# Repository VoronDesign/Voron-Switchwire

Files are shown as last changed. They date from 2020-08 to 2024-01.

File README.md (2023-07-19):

# Voron Switchwire
**[CLICK HERE TO DOWNLOAD](https://voron.zip/done/VSW.zip)**

The above link includes the stealthburner toolhead files which are compatible with several of the printers in the Voron lineup. 
To keep things organized, StealthBurner’s files are maintained separately. 
the Stealthburner Repository can be browsed by clicking [HERE](https://github.com/VoronDesign/Voron-Stealthburner)

Image of Voron Switchwire

The official release of the Voron Switchwire 3d printer.  You can find the BOM and any other relevant information at the [Voron Design]( http://vorondesign.com/voron_switchwire) website.

Voron Logo

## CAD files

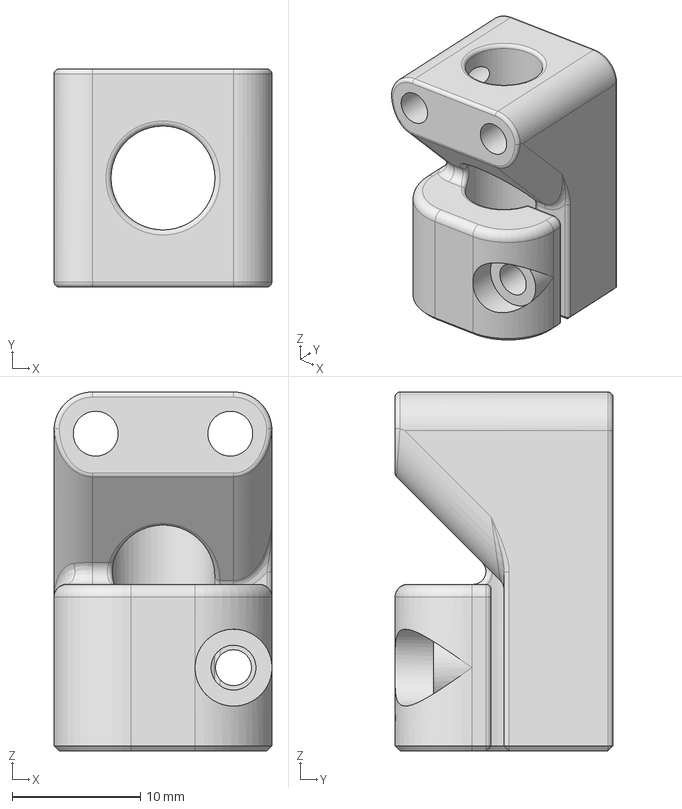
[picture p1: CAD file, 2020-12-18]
CAD/Pinion.step
17.0 x 17.0 x 28.0 mm

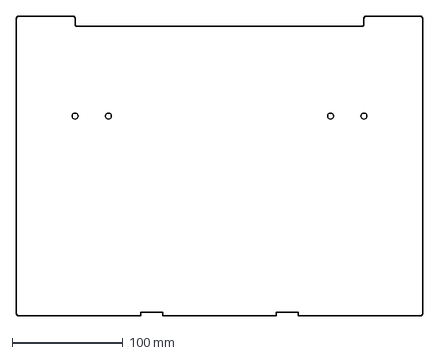
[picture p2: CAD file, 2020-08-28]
DXF/top_panel_abs.dxf
366.0 x 270.0 mm

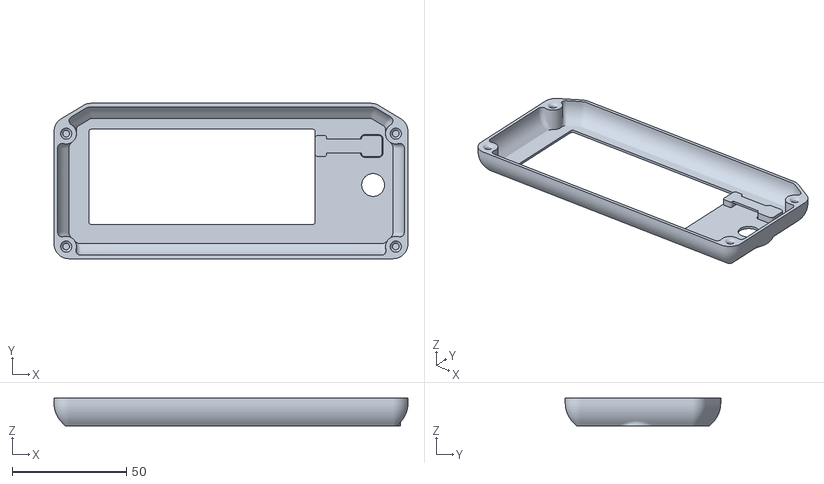
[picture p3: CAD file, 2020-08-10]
STL/Electronics/LCD/2004_(Prusa)/lcd_case_front_2004.stl
155.2 x 68.2 x 12.2

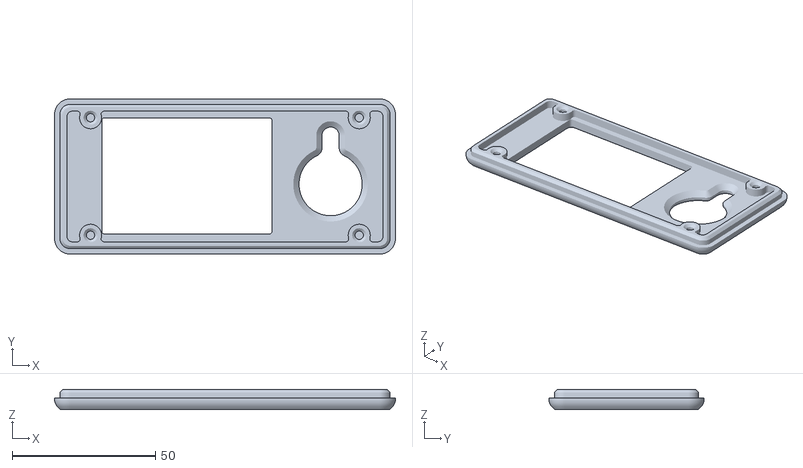
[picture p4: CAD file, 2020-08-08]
STL/Electronics/LCD/Mini12864/lcd_case_front_mini12864.stl
119.0 x 54.2 x 7.00

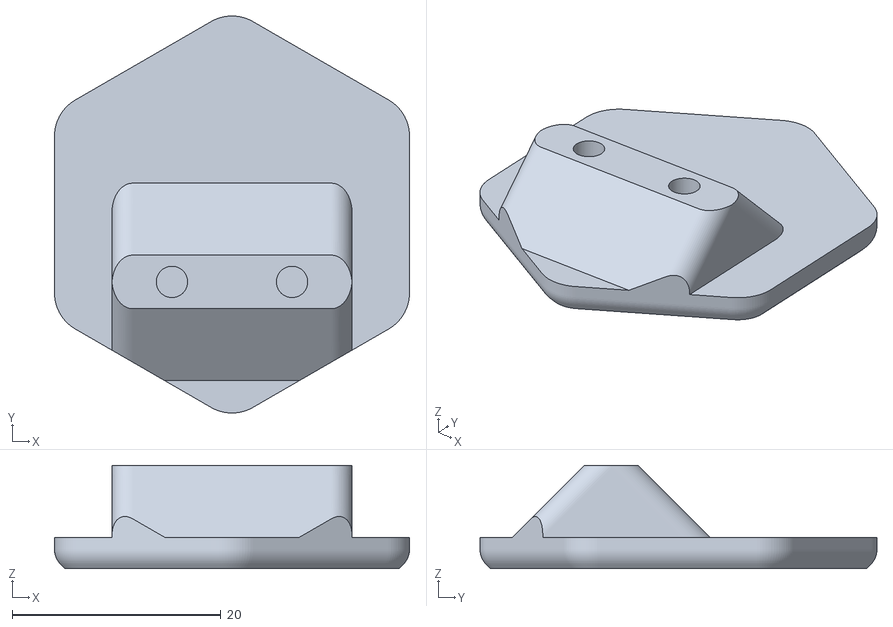
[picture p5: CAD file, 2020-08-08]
STL/Electronics/LCD/No_LCD/[a]_lcd_blank.stl
34.0 x 38.0 x 9.89

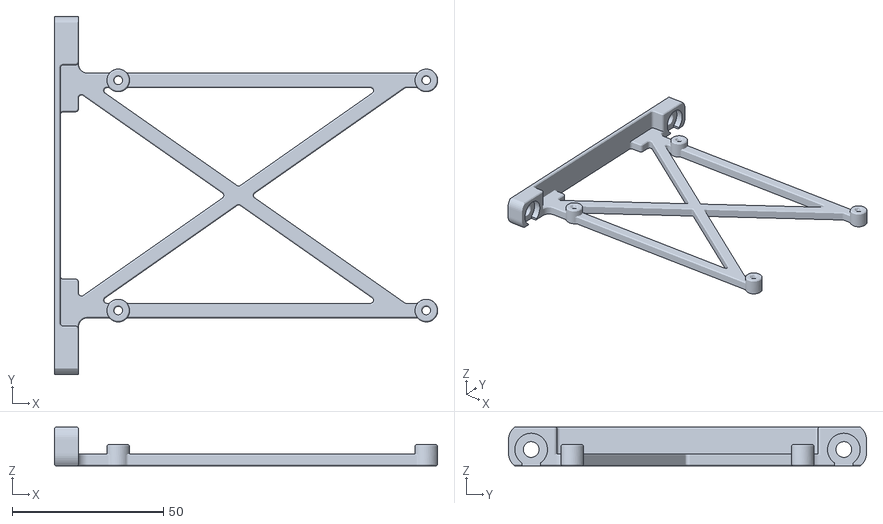
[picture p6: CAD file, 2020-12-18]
STL/Electronics/skr_mount.stl
126.8 x 118.3 x 12.8

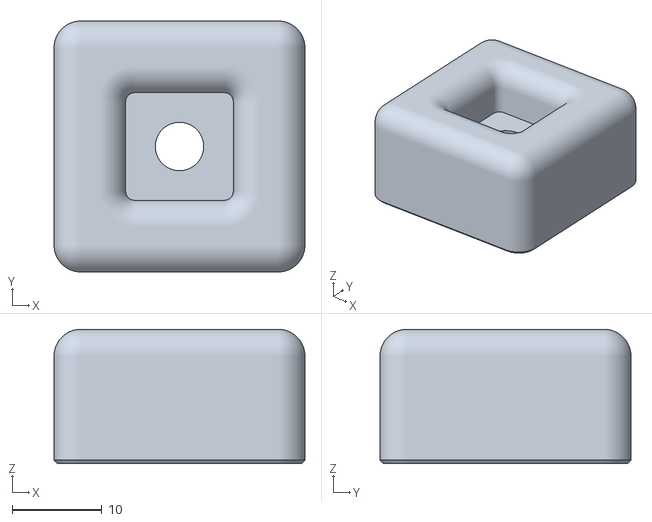
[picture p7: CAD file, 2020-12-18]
STL/foot_tpu_x4.stl
28.0 x 28.0 x 15.0

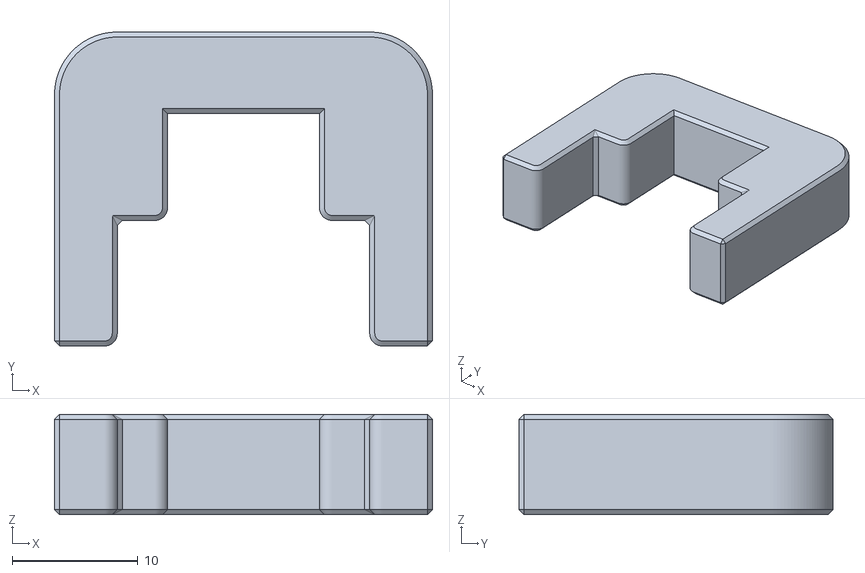
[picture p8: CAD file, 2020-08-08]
STL/Gantry/2020_MGN12_guide_x2.stl
30.1 x 25.0 x 8.00

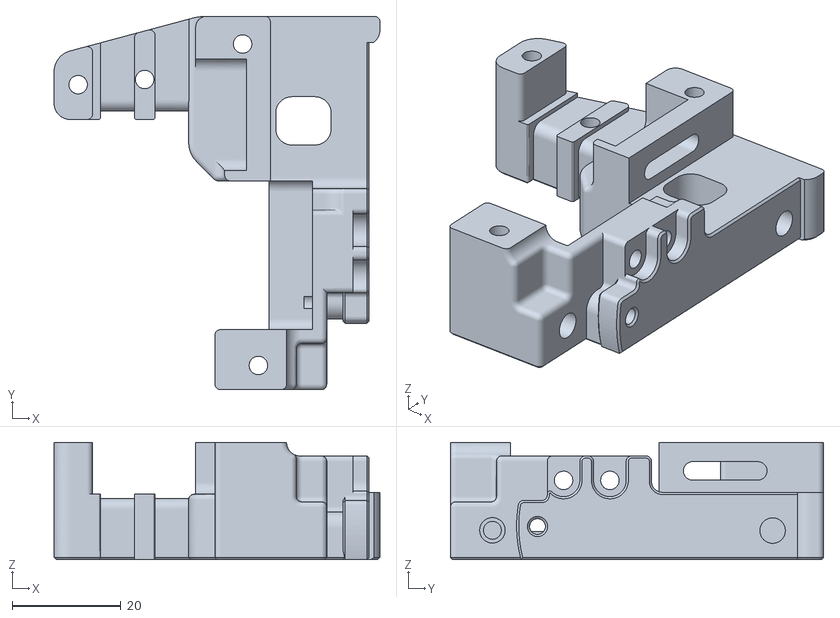
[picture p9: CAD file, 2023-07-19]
STL/Gantry/XZ_Axis/X_Carriage/x_frame_SW_left.stl
60.0 x 68.8 x 21.6

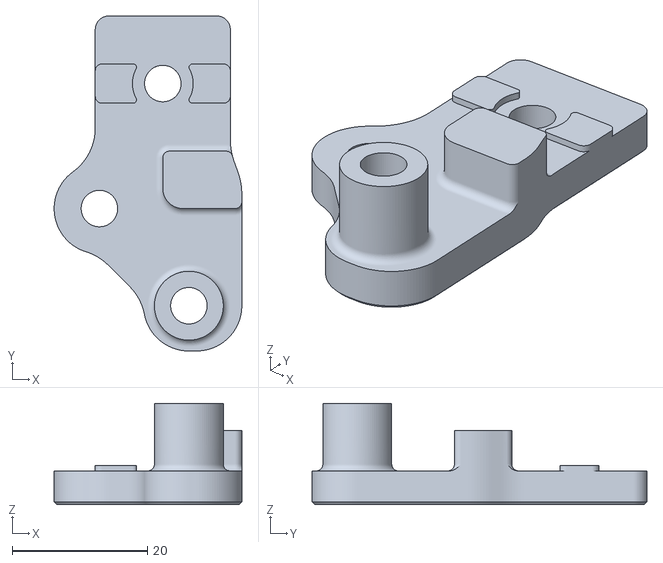
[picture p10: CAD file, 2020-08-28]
STL/Gantry/XZ_Axis/xz_block_right_b.stl
27.8 x 49.6 x 15.0

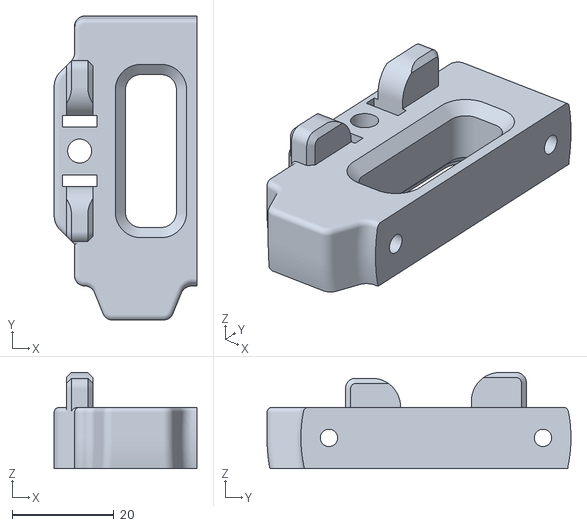
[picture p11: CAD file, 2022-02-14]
STL/Gantry/Y_Axis/y_belt_anchor_sensorless.stl
28.0 x 59.7 x 18.8

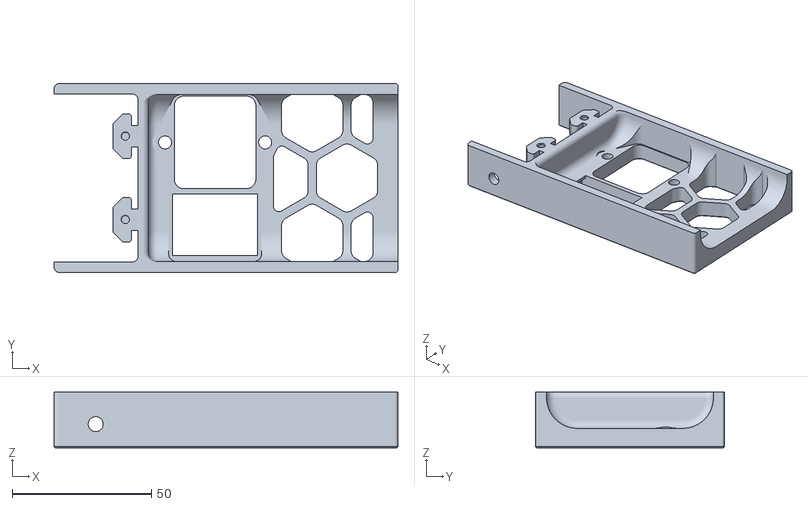
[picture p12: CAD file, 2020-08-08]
STL/Grills/grill_rear_left_filtered.stl
123.7 x 68.0 x 20.0

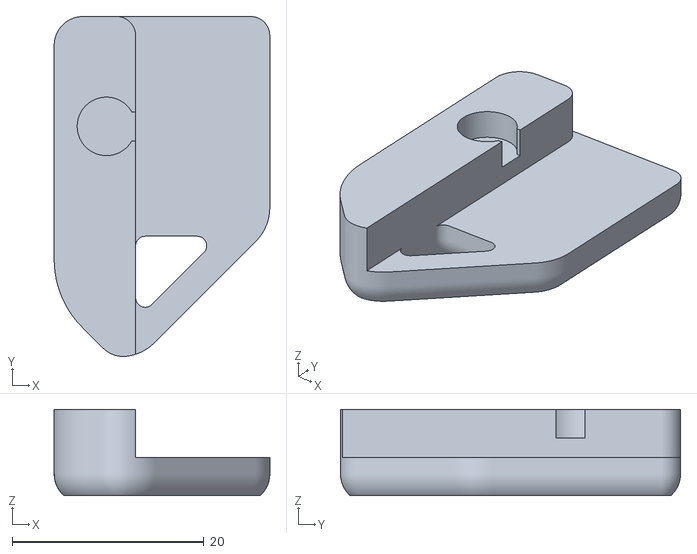
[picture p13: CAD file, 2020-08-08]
STL/Panel_Mounting/Doors/door_handle_b_x2.stl
22.5 x 35.5 x 9.00

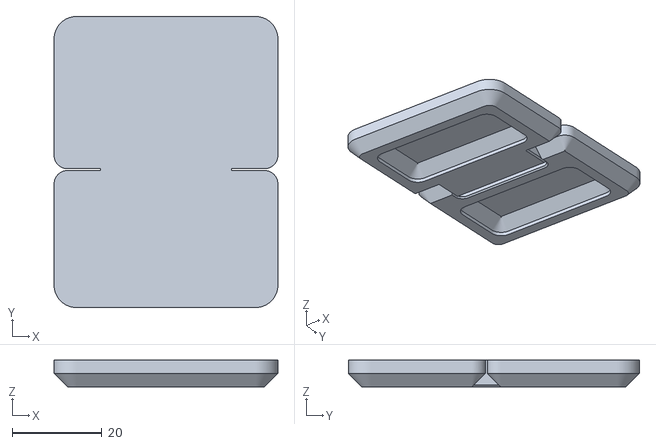
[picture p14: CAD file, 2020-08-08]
STL/Panel_Mounting/side_strap_x4.stl
50.0 x 65.0 x 6.00

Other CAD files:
DXF/deck_panel_right.dxf
STL/Electronics/LCD/2004_(Prusa)/lcd_case_rear_2004.stl
STL/Electronics/LCD/Mini12864/lcd_case_rear_mini12864.stl
STL/Electronics/skr_mount_rotated.stl
CAD/Pinion.f3d
DXF/bottom_panel.dxf
DXF/deck_panel_left.dxf
DXF/rear_panel.dxf
DXF/rear_panel_abs.dxf
DXF/side_panel_left.dxf
DXF/side_panel_left_abs.dxf
DXF/side_panel_right.dxf
DXF/side_panel_right_abs.dxf
DXF/top_panel.dxf
STL/Electronics/3030_wire_clip.stl
STL/Electronics/LCD/2004_(Prusa)/[a]_lcd_knob.stl
STL/Electronics/PS_2020_Mount_x2.stl
STL/Electronics/PS_3030_Mount_x2.stl
STL/Electronics/einsy_rambo_mount.stl
STL/Electronics/raspberry_pi_mount.stl
STL/Electronics/raspberry_pi_zero_shelf.stl
STL/Electronics/rs_25_mount.stl
STL/Electronics/skr_mini_e3_mount.stl
STL/Gantry/3030_MGN12_guide_x2.stl
STL/Gantry/XZ_Axis/X_Carriage/[a]_x_bearing_block.stl
STL/Gantry/XZ_Axis/X_Carriage/[a]_xz_belt_clip_x2.stl
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

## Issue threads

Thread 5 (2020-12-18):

Build guide of some sorts?

tobyworks, 2020-12-18:
Maybe I'm blind but i've searched for build guides or how to's or anything close to that and i couldn't find one? is it still on the to-do?

raymondh2, 2020-12-18:
The manual is in progress still

mild-lemon, 2020-12-31:
Any target date for a pre-alpha version of the manual?
I'm considering building a Switchwire, but without a preliminary manual I'm sort of lost. No idea on how to use the parts and printable jigs...

raymondh2, 2021-01-01:
There is an alpha version of the manual pinned in the Switchwire help channel on the Voron Discord.

Closed 2021-01-01.

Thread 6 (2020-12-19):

latch_shuttle.stl needs an [a] tag

9ary, 2020-12-19:
This part is red in the CAD and also in the V2.4 manual, it doesn't really matter in the end since it's not visible, but I figured I'd let y'all know anyway.

raymondh2, 2021-02-22:
Fixed in PR #19

Closed 2021-02-22.

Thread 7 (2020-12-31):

Update printer config to latest display menu options

raymondh2, 2020-12-31:
Current config files are based on old Klipper menu system. Suggest updating or removing them.

Closed 2021-02-06.

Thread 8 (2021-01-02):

Update printer to remove endstop_position from [stepper z]

jdlongenecker, 2021-01-02:
20201213: It is not valid to specify a Z "position_endstop" when using "probe:z_virtual_endstop". An error will now be raised if a Z "position_endstop" is specified with "probe:z_virtual_endstop". Remove the Z "position_endstop" definition to fix the error.

Closed 2021-02-06.

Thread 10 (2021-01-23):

Update to rotation_distance

raymondh2, 2021-01-23:
Update Klipper configs to use rotation_distance.

raymondh2, 2021-12-18:
Fixed in #31

Closed 2021-12-18.

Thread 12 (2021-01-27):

Error in assembly manual - page 10 and 14 - Wrong extrusions marked

internallabworks, 2021-01-27:
On page 10, the uprights for Z is marked for use for the bottom cross extrusions.
And on page 14 the cross extrusions are marked for use on Z
Example on page 10:
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

Makes the bottom look funky wide :)
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

jakep82, 2021-05-25:
This issue was reintroduced in the manual that was published 19 days ago. I just built my frame and discovered it called for the wrong extrusions, requiring me to disassemble and start over.

raymondh2, 2021-05-25:
This issue has been resolved by #13

Closed 2021-01-30.

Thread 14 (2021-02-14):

RE:  Addition to switchwire BOM

bigjoe4265, 2021-02-14:
6x6x3mm y-carriage spacers are available from McMaster.  Buy 10 instead of 9, price goes down from $2.11 to $1.79 each.  These should work, but haven't received them to verify the fit.

https://www.mcmaster.com/92871A009/

digitalfrost, 2021-02-22:
This information should be added to the sourcing guide not to the BOM.

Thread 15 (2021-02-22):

Missing Part in BOM: Bowden tube

digitalfrost, 2021-02-22:
On the page https://vorondesign.com/voron_switchwire when clicking on the BOM button, the BOM displayed and available for download as voron_switchwire_bom.csv seems to have a part missing.

It is not consistent with the information given in the sourcing guide: https://vorondesign.com/sourcing_guide?model=VS

Under the Misc section the
_Bowden Tube (4mm OD, 3mm ID) | 3m_
listed in the sourcing guide is missing from the downloadable sourcing guide.

raymondh2, 2021-02-22:
The 3mm id bowden tube is an optional item on Switchwire

Closed 2021-02-22.

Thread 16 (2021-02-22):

Inconsistencies between BOM and Sourcing Guide

digitalfrost, 2021-02-22:
There are inconsistencies between the sourcing guide https://vorondesign.com/sourcing_guide?model=VS and the BOM available on the  https://vorondesign.com/voron_switchwire page

Under the **Misc** section in the sourcing guide there is
_BMG Extruder Hardware Kit_
In the downloadable BOM this is listed in the **Motion** section as
_BMG Extruder Componnets Kit_

Under the **Motion** section in the sourcing guide there is
_Key-bak Super48 13oz_
this is listed in the **Misc** section in the downloadable BOM as
_Key-Bak Super 48 Retractable Keychain_
(I think this description is clearer as to what the item is)

renjie-teo, 2022-04-02:
Hi I've come across the link to this issue and would like to chime in for the keybak if it could be named as such:
Key-bak Super48 36" 13oz
The name is the full name listed on amazon as well so it would be clear to voron builders that they are supposed to purchase the 36" 13oz version instead of getting the 48" 8oz version by accident (perhaps also provide a warning since many who were unaware made the same mistake)

Thank you!

nemgrea, 2023-03-01:
this has been fixed

Closed 2023-03-01.

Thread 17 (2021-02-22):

BOM Electronics vs Sourcing Guide Electronics

digitalfrost, 2021-02-22:
The downloadable BOM has an **Electronics** section with 20 items.

The sourcing guide has an an **Electronics** section with 13 items.

The sourcing guide has a **"Controller"** section with 6 items which the downloadable BOM does not have
some of these items can be found in the **Electronics** section of the dowloadable BOM
for example
_SKR Mini E3 V2_
but others are not listed in the BOM at all for example
_MicroSD Card_

nemgrea, 2021-02-22:
things like the c14 cord and the micro usb cable do not benefit from having a line in the sourcing guide as local prices for these items are typically extremely variable and providing a link for you to buy one serves no benefit. all c14 cords are approved cords you cant buy a bad one, thus a guide for sourcing that component is not necessary

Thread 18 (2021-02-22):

Number of USB Cable A-male B-male

digitalfrost, 2021-02-22:
The BOM indicates

_USB Cable A-male B-male_  **QTY:** _2_

The sourcing guide indicates

_USB Cable A-male Mini B-male (Included with SKR Mini)_  **QTY:** _1_

nemgrea, 2021-02-22:
fixed

Closed 2021-02-22.

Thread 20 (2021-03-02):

The connector cover on directfeed is incompatiable with generic steppers

dingyifei, 2021-03-02:
I'm not sure which connector cover in the afterburner repo is the one in switchwire.

I got this wacky stepper motor from Taobao. With this motor, the following issues would occur:

- The cable cover will break in the installation
- The 20mm screws are to be too short to reach the threads
- The threaded insert on the clockwork can't be used to secure the cable cover since it's further away.

The image below is the stepper:
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

dingyifei, 2021-03-03:
NVM... looks like a mod exist for this issue

Closed 2021-03-03.

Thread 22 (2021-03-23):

[a] prefix in stl file names

tobyworks, 2021-03-23:
Some stl's have [a] as a prefix. What does this mean?

eddietheengineer, 2021-03-23:
This means that you can print them in an accent color to give your printer a bit more character 👍🏼

tobyworks, 2021-03-23:
Thanks for the rapid response!

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

Closed 2021-03-23.

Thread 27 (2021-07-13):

Incorrect / Old Klipper Configs.

cobramike, 2021-07-13:
After a full month of testing and fine tuning i made a Correct fysetc spider printer.cfg.
The old firmware are a very old Klipper config. Also extruder settings are incorrect. That is causing extreme heat Extruder Motor.
Here is my Printer.cfg for the fysetc spider

[https://pastebin.com/VuUeXtPq](url)

#####################################################################
# 	Printer settings
#####################################################################
[mcu]
serial: /dev/ttyAMA0
restart_method: command

[printer]
kinematics: corexz
max_velocity: 200
max_accel: 4000
max_accel_to_decel: 4000
max_z_velocity: 50
max_z_accel: 1000
square_corner_velocity: 4.0

[input_shaper]
shaper_freq_x: 52
shaper_freq_y: 54.5
shaper_type: mzv

[stepper_x]
step_pin: PE11
dir_pin: !PE10
enable_pin: !PE9
endstop_pin: ^PB14
position_endstop: 250
position_min: 0
position_max: 250
homing_speed: 70
homing_positive_dir: true
rotation_distance: 40
full_steps_per_rotation: 200
microsteps: 16

[tmc2209 stepper_x]
uart_pin: PE7
run_current: 0.5
hold_current: 0.3
interpolate: True
stealthchop_threshold: 250

[stepper_y]
step_pin: PD8
dir_pin: !PB12
enable_pin: !PD9
endstop_pin: ^PB13
position_endstop: 250
position_min: 0
position_max: 250
homing_speed: 70
homing_positive_dir: true
rotation_distance: 40
full_steps_per_rotation: 200
microsteps: 16

[tmc2209 stepper_y]
uart_pin: PE15
run_current: 0.6
hold_current: 0.4
interpolate: True
stealthchop_threshold: 250

[stepper_z]
step_pin: PD14
dir_pin: !PD13
enable_pin: !PD15
endstop_pin: probe:z_virtual_endstop
position_max: 235
homing_speed: 40
position_min: -3.0
rotation_distance: 40
full_steps_per_rotation: 200
microsteps: 16

[tmc2209 stepper_z]
uart_pin: PD10
run_current: 0.5
hold_current: 0.3
interpolate: True
stealthchop_threshold: 250

[bed_mesh]
speed: 150
horizontal_move_z: 10
mesh_min: 25,35.0
mesh_max: 225.0,220
probe_count: 6,6
algorithm: bicubic
fade_start: 1
fade_end: 10
fade_target: 0

[probe]
pin: PA3
x_offset: 0.0
y_offset: 25.0
#z_offset: 0
speed: 40.0

[homing_override]
axes: z
set_position_z: 0
gcode:
    G90
    G0 Z5 F500
    G28 X0 Y0
    G0 X125 Y100 F9000
    G28 Z0
    G0 Z5 F500

#####################################################################
# 	Extruder
#####################################################################

#	E0 on MCU X/Y
[extruder]
max_extrude_only_distance: 1000.0
step_pin: PD5
dir_pin: !PD6
enable_pin: !PD4
##	Update value below when you perform extruder calibration
##	If you ask for 100mm of filament, but in reality it is 98mm:
##	rotation_distance = <previous_rotation_distance> * <actual_extrude_distance> / 100
##  22.6789511 is a good starting point
rotation_distance: 22.225372078 	#Bondtech 5mm Drive Gears
##	Update Gear Ratio depending on your Extruder Type
##	Use 50:17 for Afterburner/Clockwork (BMG Gear Ratio)
##	Use 80:20 for M4, M3.1
gear_ratio: 50:17				#BMG Gear Ratio
microsteps: 16
full_steps_per_rotation: 200	#200 for 1.8 degree, 400 for 0.9 degree
nozzle_diameter: 0.400
filament_diameter: 1.75
heater_pin: PB15
##	Validate the following thermistor type to make sure it is correct
sensor_type: ATC Semitec 104GT-2
sensor_pin: PC0
min_temp: 10
max_temp: 270
max_power: 1.0
min_extrude_temp: 170
control = pid
pid_kp = 26.213
pid_ki = 1.304
pid_kd = 131.721
##	Try to keep pressure_advance below 1.0
pressure_advance: 0.05
##	Default is 0.040, leave stock
pressure_advance_smooth_time: 0.040

##	E0 on MCU X/Y
##	Make sure to update below for your relevant driver (2208 or 2209)
[tmc2209 extruder]
uart_pin: PD7
interpolate: false
run_current: 0.45
hold_current: 0.30
sense_resistor: 0.110
stealthchop_threshold: 0

#####################################################################
# 	END Extruder
#####################################################################

#####################################################################
# 	Probe Settings
#####################################################################
# Textured Bed
#[probe]
#z_offset = 4.910

# Flat Bed
[probe]
z_offset = 4.740

#####################################################################
# 	End Probe Settings
#####################################################################

[heater_bed]
heater_pin: PB4
sensor_type: NTC 100K MGB18-104F39050L32
sensor_pin: PC3
control = pid
pid_kp = 60.695
pid_ki = 1.073
pid_kd = 858.069
min_temp: 0
max_temp: 130

#######################################
#### Enclosure Temp Sensor Section ####
#######################################
[temperature_sensor enclosure_temp]
sensor_type: NTC 100K beta 3950
sensor_pin: PC1
min_temp: 0
max_temp: 100
gcode_id: C

#######################################
#### Raspberry Temp Sensor Section ####
#######################################
[temperature_sensor Pi]
sensor_type: rpi_temperature
min_temp: 0
max_temp: 90

[fan]
pin: PB2

# thermally controlled hotend fan
[heater_fan my_nozzle_fan]
pin: PB1
max_power: 1.0
kick_start_time: 0.100
heater: extruder
heater_temp: 50.0
fan_speed: 1.0

[virtual_sdcard]
path: ~/gcode_files

#####################################################################
#	Displays
#####################################################################

[display]
#   mini12864 LCD Display
lcd_type: uc1701
cs_pin: PC11
a0_pin: PD2
rst_pin: PC10
encoder_pins: ^PC6,^PC7
click_pin: ^!PA8
contrast: 63
#spi_bus: spi1
spi_software_mosi_pin: PA7
spi_software_miso_pin: PA6
spi_software_sclk_pin: PA5

[neopixel fysetc_mini12864]
#   To control Neopixel RGB in mini12864 display
pin: PC12
chain_count: 3
chain_count: 60
initial_RED: 0.1
initial_GREEN: 0.5
initial_BLUE: 0.0
color_order: RGB

#   Set RGB values on boot up for each Neopixel.
#   Index 1 = display, Index 2 and 3 = Knob
[delayed_gcode setdisplayneopixel]
initial_duration: 1
gcode:
    SET_LED LED=fysetc_mini12864 RED=1 GREEN=0 BLUE=0 INDEX=1 TRANSMIT=0
    SET_LED LED=fysetc_mini12864 RED=1 GREEN=0 BLUE=0 INDEX=2 TRANSMIT=0
    SET_LED LED=fysetc_mini12864 RED=1 GREEN=0 BLUE=0 INDEX=3

#####################################################################
#	LED Control
#####################################################################

# Chamber Lighting
[output_pin caselight]
pin: PB3
#max_power: 1.0
#kick_start_time: 0.5
pwm: true
shutdown_value: 0
value: 100
cycle_time: 0.01
scale: 100

# Lighting Control
[gcode_macro lights_off]
gcode:
    SET_PIN PIN=caselight VALUE=0

[gcode_macro lights_on]
gcode:
    SET_PIN PIN=caselight VALUE=100

#####################################################################
#	End LED Control
#####################################################################

#####################################################################
#	Macros
#####################################################################
[display_status]

[pause_resume]

[gcode_macro CANCEL_PRINT]
rename_existing: BASE_CANCEL_PRINT
gcode:
    M107
    TURN_OFF_HEATERS
    DISABLE_MOTORS
    CLEAR_PAUSE
    SDCARD_RESET_FILE
    BASE_CANCEL_PRINT

[gcode_macro PAUSE]
rename_existing: BASE_PAUSE
gcode:
    SAVE_GCODE_STATE NAME=PAUSE_state
    BASE_PAUSE
    G91
    G1 E-1.7 F2100
    G90
    _PARK_HEAD

[gcode_macro RESUME]
rename_existing: BASE_RESUME
gcode:
    G91
    G1 E1.7 F2100
    G91
    RESTORE_GCODE_STATE NAME=PAUSE_state MOVE=1
    BASE_RESUME

[gcode_macro DISABLE_MOTORS]
gcode:
    M18

[gcode_macro PRINT_START]
gcode:
    lights_on
    M117 Homing...
    M140 S{BED_TEMP}                         ; set bed final temp
    M104 S{EXTRUDER_TEMP}                         ; set extruder final temp
    M190 S{BED_TEMP}                         ; wait for bed final temp
    M109 S{EXTRUDER_TEMP}                         ; wait for extruder final temp
    BED_MESH_CLEAR

    G21 ; set units to millimeters
    G90 ; use absolute coordinates
    M83 ; use relative distances for extrusion
    G28 ; home all axes
    G1 Z20 F3000                   ; move nozzle away from bed
    BED_MESH_CALIBRATE
    G92 E0
    G90
    G0 X13 Y13 F6000
    G0 Z0.4
    G91
    G1 X120 E30 F1200
    G1 Y1
    G1 X-120 E30 F1200
    G92 E0
    G90
    G1 Z20.0 F3000
    G92 E0
    M117 Printing....

[gcode_macro PRINT_END]
#   Use PRINT_END for the slicer ending script - please customise for your slicer of choice
gcode:
    M400                           ; wait for buffer to clear
    G92 E0                         ; zero the extruder
    G1 E-1.0 F3600                ; retract filament
    G91                            ; relative positioning
    G0 Z1.00 X20.0 Y20.0 F20000    ; move nozzle to remove stringing
    TURN_OFF_HEATERS
    M107                           ; turn off fan
    G1 Z50 F3000                    ; move nozzle up 20mm
    G90                            ; absolute positioning
    G0  X0 Y220 F3600            ; park nozzle at rear
    BED_MESH_CLEAR
    M117 Finished!
    lights_off

#####################################################################
#	End Macros
#####################################################################

#*# <---------------------- SAVE_CONFIG ---------------------->
#*# DO NOT EDIT THIS BLOCK OR BELOW. The contents are auto-generated.
#*#

raymondh2, 2021-12-18:
Fixed in #31

Closed 2021-12-18.

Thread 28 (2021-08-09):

Assembly Manual repeats

spoonypirate, 2021-08-09:
In the Assembly manual, pages 74 and 75 for the Clockwork assembly are repeated, overwriting the instructions for the guidler and latch install.

TaffoFox, 2021-08-24:
I came to add this issue however you have done it already so thank you

Closed 2021-11-26.

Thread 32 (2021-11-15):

about MOS for sw

papagoWBT, 2021-11-15:
It says you need two MOSs in BoM, but it's not written in the sourcing guide. Do I have to buy MOS? How can I connect if I need MOS or not?

nemgrea, 2023-01-18:
fixed

Closed 2023-01-18.

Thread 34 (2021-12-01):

New printhead

Kevincondor, 2021-12-01:
hello,i'll like to use a Biqu H2 extruder on this,but cannot find a mount plate compatible

raymondh2, 2021-12-18:
You'll have to create your own as we don't have plans to support that extruder.

Closed 2021-12-18.

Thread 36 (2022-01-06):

switchwire stl and cad files out of synch

phongshader, 2022-01-06:
it looks like https://github.com/VoronDesign/Voron-Switchwire/blob/master/STL/Gantry/XZ_Axis/%5Ba%5D_upper_idler_support_b_left.stl and https://github.com/VoronDesign/Voron-Switchwire/blob/master/STL/Gantry/XZ_Axis/%5Ba%5D_upper_idler_support_b_right.stl are a different version than what is contained here https://github.com/VoronDesign/Voron-Switchwire/blob/master/CAD/Bowden_Dual_Adapter.step. Is it possible to get the updated files in step or f3d?

nemgrea, 2023-03-01:
the files youve linked are not the same parts, the bowden toolhead CAD is not intended to contain any of the idler parts

Closed 2023-03-01.

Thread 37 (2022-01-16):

Several files have been updated but there's no new release

maximilian-foerg, 2022-01-16:
I'm currently building a Switchwire and downloaded the latest Release from 28 of August in 2020. While printing the parts, I realized that an old version of the Afterburner is included in this release. A closer look into the repository unveiled that several STLs have been updated after this release. I think there should be a "Switchwire 1.1" or "Switchwire 1.0.1" release for that. At least the update of the Afterburner would have been worth it after all. People have been downloading an outdated release to build the switchwire for a year and a half now....

Closed 2022-12-20.

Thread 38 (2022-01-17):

Bearing block for SW unnecessary?

crashmaxx, 2022-01-17:
[a]_x_bearing_block_SW_beta0.stl is only used for SW, but the V2/Trident MGN12 carriage can mount to the same rail without this extra piece.

I suggest changing the SW carriage to mount directly to the rail, the same as V2/Trident. This would save an extra part, 4 screws, and 4 heat set inserts. I was able to redesign the original SW carriage in this way and have used it without issues.

Maybe I am missing an advantage of the extra block, but I suspect it exists simply because it was designed first. When Trident was designed, a better way to make the carriage was discovered.

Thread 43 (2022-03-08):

Manual only shows Probe Signal Wire Connection, Website is also unclear

ChaosBlades, 2022-03-08:
The Switchwire manual shows the diode and signal wire connection but just shows the positive and negative probe wires going to nothing.
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

The website could be more clear as well.
https://docs.vorondesign.com/build/electrical/sw_miniE3_v20_wiring.html
**Says...**
Plug Probe GND and Signal (with BAT85 diode) in to Z-STOP
Connect Probe +V to VIN in terminal next to HB

**Sound Say...**
Plug Probe Ground (Blue Wire) to Z-STOP GND and Signal (Black Wire) with BAT85 diode (black band facing away from connector) in to Z-STOP PC2
Connect Probe Positive (Brown Wire) to POWER 12/24V (The one just to the Left of BED)

ChaosBlades, 2022-03-08:
Also, The Mainboard Breakout Board pictured on page 125, I can't find anything on this board. It isn't linked to, I cant find any reference to it anywhere, and I certainly can't find anywhere to buy it. All the Toolhead PCB listings for purchase only come with the Toolhead PCB. It also shows the Probe being connected from a 3-pin connector to a 2-pin connector via 1 Brown Wire. So it is not clear how this is supposed to be connected even if I could find anything on this mysterious board.
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

Onlywavesmdp, 2022-06-18:
I have the same problem, were you able to solve it?

T4KUUY4, 2025-01-23:
@ChaosBlades
Hoy there, late update but its an update :D

The board you are seeing here is an LDO specific toolhead board.
Looks like we forgot to add a tag to that page stating that. This is now fixed within the next manual update.

~Takuya

Closed 2025-01-23.

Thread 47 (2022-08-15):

Y-CARRIAGE

anlox31, 2022-08-15:
where are you find y carriage cad file ?

jernejp21, 2022-08-15:
All the CAD models are in a single CAD file - printer assembly file.
https://github.com/VoronDesign/Voron-Switchwire/blob/master/CAD/Switchwire_Assembly_v1.13.f3d

anlox31, 2022-08-18:
can i used for hot bed size 220mm ?

nemgrea, 2022-12-20:
this seems to be a request for help and not a valid issue report

Closed 2022-12-20.

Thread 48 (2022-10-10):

Belt clamp Switchwire orientation

Grooviee, 2022-10-10:
I think the orientation of the [a]_Belt_Clamp_SW_x2.STL is wrong and should be rotated the same as the [a]_xz_belt_clip_x2.stl in the Switchwire-github.

Closed 2022-10-10.

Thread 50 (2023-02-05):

Assembly manual does not show the SHCS bolt required for display assy

3dRikal, 2023-02-05:
**OBSERVED**: On page 110 of the SW assembly manual, 2 SCHS bolts are required to set the display in place. 2 bolts are shown but no details are given

**EXPECTED**: Bolts should be labeled **M3x16 SHCS**

**Manual version reviewed:** 2021-11-26

nemgrea, 2023-12-20:
https://github.com/VoronDesign/Voron-Switchwire/pull/59

Closed 2023-12-20.

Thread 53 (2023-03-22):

Manual Page 70 - Mis-labeled M5 BHCS

sirjaymz, 2023-03-22:
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

asdasdwa-v02679, 2023-05-17:
Good catch, here is a updated version of the page plus a higher rez of just the edited assembly for the future convenience of the Manual team!
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

nemgrea, 2023-12-20:
https://github.com/VoronDesign/Voron-Switchwire/pull/59

Closed 2023-12-20.

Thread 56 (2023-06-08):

Wich configuration for Swichtwire withg SKR 1.3

JuliusCesar2017, 2023-06-08:
Hi there,

so i bought a used switchwire with an skr 1.3 and a pi 4 b.

The problem is the printer has no firmware on the sd card of the skr.

So i tought taht seeting it up completly new would solve this.

But i am stuck at the point of the voron instructions for selecting the software config out of the three ones.

My skr 1.3 board is not listed ?

Would be awsome if someone could help.

Thanks for your time.

Closed 2024-02-29.

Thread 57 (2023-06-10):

Filler text on manual page 120

reimda, 2023-06-10:
In the PDF docs on page 120, in a caption about premade cables there is filler text instead of a description of the cables.

The filler text is

> Uptis velicatur sequam sunte
> voloresed magnisit inihit,
> ommodicia vit ad quis maio.

nemgrea, 2023-12-20:
https://github.com/VoronDesign/Voron-Switchwire/pull/59

Closed 2023-12-20.

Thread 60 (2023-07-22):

Purge line g code causing issue during print start.

Johnn201, 2023-07-22:
Using the switchwire skr mini e3 v3 config file,and superslicer with PRINT_START in the start gcode after print start having the Purge Line Gcode uncommented I get error:
Extruder not hot enough
7:15 AM
Move out of range: 5.000 5.000 3.000 [0.000]
7:15 AM
Move out of range: 5.000 5.000 3.000 [0.000]
If I comment it out it prints normally.
[klippy.log](https://github.com/VoronDesign/Voron-Switchwire/files/12136471/klippy.log)

Johnn201, 2023-07-23:
I have gotten rid of all but the error Extruder not hot enough by changing G0 X5 Y5 to G0 X20 Y20 F6000 but still get Extruder not hot enough unless I preheat the extruder, so still looking for a solution.

Johnn201, 2023-07-23:
[Scientist_Test_90mm1.txt](https://github.com/VoronDesign/Voron-Switchwire/files/12138885/Scientist_Test_90mm1.txt)

nemgrea, 2023-07-24:
add

M109
M190

to the beginning of the purge g code

Johnn201, 2023-07-25:
I'll try that thank you.

Johnn201, 2023-07-26:
The M109
       M190
Also did not fix the heating problem
Should "Only custom start GCode be checked in superslicer printer settings?

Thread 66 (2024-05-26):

Manual: Red and black power cables are both attached to V+ screw terminals of DC supply

chuckthedudeman, 2024-05-26:
Red and black power cables are both attached to V+ screw terminals of DC supply
Manuals/Assembly_Manual_SW.pdf - Pg 100 - DC POWER - PREMADE CABLES

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

T4KUUY4, 2025-01-23:
fixed in current rev.

Closed 2025-01-23.

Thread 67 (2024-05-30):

manual: Red and black polarity is reversed on the Bed Heater Wiring / Heated Bed - pg 113

chuckthedudeman, 2024-05-30:
manual: Red (Vcc) and black (and) polarity is reversed on the Bed Heater Wiring / Heated Bed - pg 113

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

T4KUUY4, 2025-01-23:
fixed in current rev.

Closed 2025-01-23.

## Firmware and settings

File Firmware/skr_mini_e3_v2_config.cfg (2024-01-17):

## *** THINGS TO CHANGE/CHECK: ***
## MCU paths                             [mcu] section
## Thermistor types                      [extruder] and [heater_bed] sections - See https://www.klipper3d.org/Config_Reference.html#common-thermistors for common thermistor types
## PID tune                              [extruder] and [heater_bed] sections
## Fine tune E steps                     [extruder] section

## For wiring directions please see https://docs.vorondesign.com/build/electrical/sw_miniE3_v20_wiring.html

## Webclient config files. Uncomment one depending on UI being used.
#[include mainsail.cfg]
#[include fluidd.cfg] 

[printer]
kinematics: corexz
max_velocity: 200
max_accel: 1000
max_z_velocity: 50
max_z_accel: 1000
square_corner_velocity: 4.0

[mcu]
###Change to device found by "ls -l /dev/serial/by-id/" with just one this MCU connected to Pi
serial: /dev/serial/by-id/usb-Klipper_lpc1768_XXXXXXXXXXXXXXXXXXXXX

[static_digital_output usb_pullup_enable]
pins: !PA14

#####################################################################
#   X Stepper Settings
#####################################################################

######
# Motor -XM
# Endstop - X-STOP
###############
[stepper_x]
step_pin: PB13
dir_pin: PB12
enable_pin: !PB14
rotation_distance: 40
full_steps_per_rotation: 200
microsteps: 32
endstop_pin: ^PC0
position_endstop: 250
position_min: 0
position_max: 250
homing_speed: 70
homing_positive_dir: true

[tmc2209 stepper_x]
uart_pin: PC11
tx_pin: PC10
uart_address: 0
run_current: 0.5
interpolate: False
stealthchop_threshold: 0

#####################################################################
#   Y Stepper Settings
#####################################################################

######
# Motor -YM
# Endstop - Y-STOP
###############
[stepper_y]
step_pin: PB10
dir_pin: PB2
enable_pin: !PB11
rotation_distance: 40
full_steps_per_rotation: 200
microsteps: 32
## Ucomment one of the following:
## Switch-based endstop for Y
#endstop_pin: ^PC1 
## Sensorless endstop for Y
#endstop_pin: tmc2209_stepper_y:virtual_endstop
#homing_retract_dist: 0 # Uncomment this line too
#diag_pin: ^PC1 # Uncomment this line too
position_endstop: 250
position_min: 0
position_max: 250
homing_speed: 70
homing_positive_dir: true

[tmc2209 stepper_y]
uart_pin: PC11
tx_pin: PC10
uart_address: 2
run_current: 0.5
interpolate: False
stealthchop_threshold: 0
## Uncomment if using sensorless Y homing.
#driver_SGTHRS: 120 # tune this once it's working.

#####################################################################
#   Z Stepper Settings
#####################################################################

######
# Motor -ZAM
# Endstop - Z-STOP
###############
[stepper_z]
step_pin: PB0
dir_pin: PC5
enable_pin: !PB1
rotation_distance: 40
full_steps_per_rotation: 200
microsteps: 32
endstop_pin: probe:z_virtual_endstop
position_max: 250
homing_speed: 40
position_min: -3.0

[tmc2209 stepper_z]
uart_pin: PC11
tx_pin: PC10
uart_address: 1
run_current: 0.5
interpolate: False
stealthchop_threshold: 0

#####################################################################
#   Extruder Settings
#####################################################################

######
#Motor - EM
###############
[extruder]
# E0_STEP_PIN        PB3
# E0_DIR_PIN         PB4
# E0_ENABLE_PIN      PB1
# E0_UART_RX         PC11
# E0_UART_TX         PC10
step_pin: PB3
dir_pin: PB4
enable_pin: !PD2
##  Update value below when you perform extruder calibration
##  If you ask for 100mm of filament, but in reality it is 98mm:
##  rotation_distance = <previous_rotation_distance> * <actual_extrude_distance> / 100
##  22.6789511 is a good starting point
rotation_distance: 22.6789511   #Bondtech 5mm Drive Gears
##  Update Gear Ratio depending on your Extruder Type
##  Use 50:10 for Stealthburner/Clockwork 2
##  Use 50:17 for Afterburner/Clockwork (BMG Gear Ratio)
##  Use 80:20 for M4, M3.1
gear_ratio: 50:10
microsteps: 32
full_steps_per_rotation: 200
nozzle_diameter: 0.400
filament_diameter: 1.75
heater_pin: PC8
## Check what thermistor type you have. See https://www.klipper3d.org/Config_Reference.html#common-thermistors for common thermistor types.
## Use "Generic 3950" for NTC 100k 3950 thermistors
#sensor_type:
sensor_pin: PA0
min_temp: 10
max_temp: 270
max_power: 1.0
min_extrude_temp: 170
control = pid
pid_kp = 26.213
pid_ki = 1.304
pid_kd = 131.721
#Set appropriate once tuning your printer
#pressure_advance: .05
##  Default is 0.040, leave stock
# pressure_advance_smooth_time: 0.040
max_extrude_only_distance: 100.0

[tmc2209 extruder]
uart_pin: PC11
tx_pin: PC10
uart_address: 3
run_current: 0.7
hold_current: 0.3
interpolate: False

#####################################################################
#   Bed Heater
#####################################################################

######
# BED Connector
###############
[heater_bed]
heater_pin: PC9
## Check what thermistor type you have. See https://www.klipper3d.org/Config_Reference.html#common-thermistors for common thermistor types.
## Use "Generic 3950" for Keenovo heaters
#sensor_type:
sensor_pin: PC3
min_temp: 0
max_temp: 130
control: pid
pid_kp: 58.437
pid_ki: 2.347
pid_kd: 363.769

#####################################################################
#   Probe
#####################################################################

######
#Z Max Connector on Z(main) Board
#Inductive Probe
###############
[probe]
##      If your probe is NO instead of NC, add change pin to !z:P1.24
pin: ^PC2
x_offset: 0
y_offset: 25
z_offset: 0
samples: 3
samples_result: median
sample_retract_dist: 3
samples_tolerance: 0.006
samples_tolerance_retries: 3

#####################################################################
#   Fan Control
#####################################################################

######
# Electronics Fan
# Z-PROBE Connector
###############
[controller_fan my_controller_fan]
pin: PA1 
max_power: 1.00
kick_start_time: 0.200
heater: heater_bed

######
# Hot End Fan
# FAN1 Connector
###############
[heater_fan extruder_fan]
pin: PC7
heater: extruder
heater_temp: 50.0
##  If you are experiencing back flow, you can reduce fan_speed
#fan_speed: 1.0

######
# Part Cooling Fan
# FAN0 Connector
###############
[fan]
pin: PC6  # "FAN0"
cycle_time: .08
##  Depending on your fan, you may need to increase this value
##  if your fan will not start. Can change cycle_time (increase)
##  if your fan is not able to slow down effectively
kick_start_time: .25

#####################################################################
#   Homing and Bed Mesh
#####################################################################
[homing_override]
axes: z
set_position_z: 0
gcode:
    G90
    G0 Z5 F500
    G28 X0 Y0
    G0 X125 Y100 F9000
    G28 Z0
    G0 Z5 F500

[bed_mesh]
speed: 150
horizontal_move_z: 5
mesh_min: 25,35.0
mesh_max: 225.0,220
probe_count: 6,6
algorithm: bicubic
fade_start: 1
fade_end: 10
fade_target: 0

#####################################################################
#   Displays
#####################################################################
##  For the mini12864 Display, the [display] and [neopixel] must be uncommented
# mini12864 LCD Display
# connected to exp1/2
#[display]
##    mini12864 LCD Display
#lcd_type: uc1701
#cs_pin: PB8
#a0_pin: PB15
#rst_pin: PB9
#encoder_pins: ^PA9,^PA10
#click_pin: ^!PB5
#contrast: 63
#spi_software_sclk_pin: PA5
#spi_software_mosi_pin: PA7
#spi_software_miso_pin: PA6
#menu_reverse_navigation: True

#[neopixel fysetc_mini12864]
##  To control Neopixel RGB in mini12864 display
## Remember with these ones, you'll need to remove the connector header on the LCD for EXT1 + 2
## (it slides off) and reverse it for it to work on your SKR (1.3 and 1.4) board
#pin: PA15
#chain_count: 3
#initial_RED: 1
#initial_GREEN: 1
#initial_BLUE: 1
#color_order: RGB

##  Set RGB values on boot up for each Neopixel. 
##  Index 1 = display, Index 2 and 3 = Knob
#[delayed_gcode setdisplayneopixel]
#initial_duration: 1
#gcode:
#        SET_LED LED=fysetc_mini12864 RED=1 GREEN=1 BLUE=1 INDEX=1 TRANSMIT=0   # Backlit Screen colour
#        SET_LED LED=fysetc_mini12864 RED=1 GREEN=0 BLUE=0 INDEX=2 TRANSMIT=0   # Top left Knob colour
#        SET_LED LED=fysetc_mini12864 RED=1 GREEN=0 BLUE=0 INDEX=3              # Bottom right knob colour

#####################################################################
#   Case Lights
#####################################################################
[output_pin LIGHTS]
pin: PC12
value: 0
shutdown_value: 0

[gcode_macro lights_on]
gcode:
    SET_PIN PIN=LIGHTS VALUE=1.0

[gcode_macro lights_off]
gcode:
    SET_PIN PIN=LIGHTS VALUE=0.0


#####################################################################
#   Macros
#####################################################################
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

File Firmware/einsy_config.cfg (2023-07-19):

# This file contains common pin mappings for Einsy Rambo boards. To use
# this config, the firmware should be compiled for the AVR atmega2560.

# See the example.cfg file for a description of available parameters.

[stepper_x]
step_pin: PC0
dir_pin: !PL0
enable_pin: !PA7
step_distance: .0125
endstop_pin: ^PB6
#endstop_pin: tmc2130_stepper_x:virtual_endstop
position_endstop: 250
position_max: 250
homing_speed: 35.0

[tmc2130 stepper_x]
cs_pin: PG0
microsteps: 16
run_current: .3480291
hold_current: .3480291
sense_resistor: 0.220
diag1_pin: !PK2
driver_IHOLDDELAY: 8
driver_TPOWERDOWN: 0
driver_TBL: 2
driver_TOFF: 3
driver_HEND: 1
driver_HSTRT: 5
driver_PWM_FREQ: 2
driver_PWM_GRAD: 2
driver_PWM_AMPL: 235
driver_PWM_AUTOSCALE: True
driver_SGT: 3

[stepper_y]
step_pin: PC1
dir_pin: !PL1
enable_pin: !PA6
step_distance: .0125
#step_distance: (.15968 / 16)
endstop_pin: tmc2130_stepper_y:virtual_endstop
position_endstop: 230
position_max: 200
position_min: -4
homing_speed: 50
homing_retract_dist: 0

[tmc2130 stepper_y]
cs_pin: PG2
microsteps: 16
interpolate: True
run_current: .3480291
hold_current: .3480291
sense_resistor: 0.220
diag1_pin: !PK7
driver_IHOLDDELAY: 8
driver_TPOWERDOWN: 0
driver_TBL: 2
driver_TOFF: 3
driver_HEND: 1
driver_HSTRT: 5
driver_PWM_FREQ: 2
driver_PWM_GRAD: 2
driver_PWM_AMPL: 235
driver_PWM_AUTOSCALE: True
driver_SGT: 3

[stepper_z]
step_pin: PC2
dir_pin: !PL2
enable_pin: !PA5
step_distance: .0125
endstop_pin: probe:z_virtual_endstop
#endstop_pin: tmc2130_stepper_z:virtual_endstop
position_max: 230
position_min: -2.5
homing_speed: 35.0

[tmc2130 stepper_z]
cs_pin: PK5
microsteps: 16
run_current: .3480291
hold_current: .3480291
sense_resistor: 0.220
diag1_pin: !PK6
driver_IHOLDDELAY: 8
driver_TPOWERDOWN: 0
driver_TBL: 2
driver_TOFF: 3
driver_HEND: 1
driver_HSTRT: 5
driver_PWM_FREQ: 2
driver_PWM_GRAD: 2
driver_PWM_AMPL: 235
driver_PWM_AUTOSCALE: True
driver_SGT: 3

[probe]
pin: ^PB4
x_offset: 0
y_offset: 25.0
z_offset: 0
speed: 10.0
#samples: 4
#samples_result: average
#sample_retract_dist: 3.0
#samples_tolerance: 0.006
#samples_tolerance_retries: 3

[bed_mesh]
speed: 100
mesh_min: 35, 35
mesh_max: 215,190
probe_count: 5,5
mesh_pps: 2,2
algorithm: lagrange

[extruder]
step_pin: PC3
dir_pin: !PL6
enable_pin: !PA4
##  Update value below when you perform extruder calibration
##  If you ask for 100mm of filament, but in reality it is 98mm:
##  rotation_distance = <previous_rotation_distance> * <actual_extrude_distance> / 100
##  22.6789511 is a good starting point
rotation_distance: 22.6789511   #Bondtech 5mm Drive Gears
##  Update Gear Ratio depending on your Extruder Type
##  Use 50:10 for Stealthburner/Clockwork 2
##  Use 50:17 for Afterburner/Clockwork (BMG Gear Ratio)
##  Use 80:20 for M4, M3.1
gear_ratio: 50:10
nozzle_diameter: 0.400
filament_diameter: 1.750
heater_pin: PE5
## Check what thermistor type you have. See https://www.klipper3d.org/Config_Reference.html#common-thermistors for common thermistor types.
## Use "Generic 3950" for NTC 100k 3950 thermistors
#sensor_type:
sensor_pin: PF0
control: pid
pid_Kp: 22.581
pid_Ki: 1.195
pid_Kd: 106.696
min_temp: 0
max_temp: 280

[tmc2130 extruder]
cs_pin: PK4
microsteps: 16
run_current: .5
sense_resistor: 0.220
diag1_pin: !PK3

[homing_override]
axes: z
set_position_z: 0
gcode:
   G90
   G0 Z5 F600
   G28 X Y
   ##   XY Location of the Z Endstop Switch
   ##   Update X0 and Y0 to your values (such as X157, Y305) after going through
   ##   Z Endstop Pin Location Definition step.
   G0 X125 Y105 F3600 
   
   G28 Z
   G0 Z10 F1800
   
[heater_bed]
heater_pin: PG5
## Check what thermistor type you have. See https://www.klipper3d.org/Config_Reference.html#common-thermistors for common thermistor types.
## Use "Generic 3950" for Keenovo heaters
#sensor_type:
sensor_pin: PF2
#control: watermark
min_temp: 0
max_temp: 130

[fan]
pin: PH3

[heater_fan nozzle_cooling_fan]
pin: PH5

[display]
lcd_type: hd44780
rs_pin: PD5
e_pin: PF7
d4_pin: PF5
d5_pin: PG4
d6_pin: PH7
d7_pin: PG3
encoder_pins: ^PJ1,^PJ2
click_pin: ^!PH6

[mcu]
serial: /dev/ttyACM0

[printer]
kinematics: corexz
max_velocity: 300
max_accel: 3000
max_z_velocity: 5
max_z_accel: 100

[static_digital_output yellow_led]
pins: !PB7

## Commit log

2020-08-08 Initial release of VORON Switchwire
    [2020_MGN12_Guide.f3d, 2020_MGN12_guide_x2.stl, 3030_MGN12_Guide.f3d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]
2020-08-10 Adding configs, cleanup
    [2020_MGN12_Guide.f3d, 3030_MGN12_Guide.f3d, einsy_config.cfg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]
2020-08-19 Adding Bowden Y splitter CAD
    [Bowden Dual Adapter v3.f3d]
2020-08-28 Patch1 for Switchwire
    [deck_panel_right.dxf, rear_panel_abs.dxf, side_panel_left_abs.dxf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]
2020-12-18 Updates to CAD, Y Cable Chain Mounts and TPU Feet (#4)
    * Corrected folder structure naming and typos
    * Modified TPU foot to better account for lower panel thickness
    * Updated CAD files. Added Pinion and Dual Bowden CAD
    * Updated Y cable chain mounts for additional X stepper cable clearance. Added a dummy microswitch for Y sensorless homing
    * Added SKR 1.3 and 1.4 mounts
    [Bowden Dual Adapter v3.f3d, Bowden_Dual_Adapter.f3d, Bowden_Dual_Adapter.step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]
2021-01-23 remove legacy menu configs remove position_endstop from stepper_z
    [einsy_config.cfg, skr_mini_e3_v2_config.cfg]
2021-01-23 remove old moonraker config options
    [skr_mini_e3_v2_config.cfg]
2021-01-25 Create Assembly_Manual_SW.pdf
    initial commit assembly manual
2021-02-22 fix for issue 6 (#19)
    * Delete latch_shuttle.stl
    * Add files via upload
    [[a]_latch_shuttle.stl]
2021-04-21 Updated Clockwork and wire cover.
    [[a]_connector_cover.stl, [a]_guidler.stl, [a]_latch.stl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]
2021-04-21 Updated CAD with new Afterburner Clockwork changes.
2021-05-05 Update Assembly_Manual_SW.pdf
    Pages 68..78 - Updated instructions for the clockwork
2021-05-25 Update Assembly_Manual_SW.pdf (#26)
    Reverted manual to 2021-01-30
    Updated instructions on page 68..78
2021-11-26 Update Assembly_Manual_SW.pdf
    Update of manual to bring it in line with newer releases
2021-12-18 Update config file to be inline with Trident/v2 config files. (#31)
    * Update config file to be inline with Trident/v2 config files.
    * Update based on feedback.
    * Remove microsteps from stepper driver config.
    * Increase microsteps to 32, disable interpolation, set run_current equal to hold_current, disable stealthchop
    * Add option for sensorless homing of y.
    * Fix incorrect probe pin
    * remove deprecated thermistor type. Add link to klipper reference for thermistor types.
    * Update based on feedback. Remove pin definitions and replace with link to wiring guide. remove hold_current. Comment out all pressure advance settings.
    [skr_mini_e3_v2_config.cfg]
2022-02-14 Updated Afterburner single and dual bowden files.
    [bowden_dual_adapter_front_a.stl, bowden_dual_adapter_front_b.stl, bowden_dual_front_a.stl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]
2022-02-14 Added y_belt_anchor_sensorless.stl with integrated bumper for sensorless homing on the Y axis.
    [y_belt_anchor_sensorless.stl]
2022-04-30 Remove default sensor_types, convert tabs to spaces (#45)
    * Remove default sensor_types
    * Comment out sensor_types, convert tabs to spaces
    * Remove 3950 footnotes, ensure newlines at end of configs
    [einsy_config.cfg, skr_mini_e3_v2_config.cfg]
2022-12-20 SW/SKR Mini E3 v3 support (#44)
    * SKR Mini E3 v3 support
    Pins remapped from v2->v3
    * Corrected connector labels for fans
    * Corrected heater_fan PC15->PB15
    [skr_mini_e3_v3_config.cfg]
2023-07-19 stealthburner integration (#59)
    * SB stls
    * Update README.md
    * CAD
    * Update README.md
    * Update Assembly_Manual_SW.pdf
    * Update einsy_config.cfg
    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
    [Bowden_Dual_Adapter.f3d, Bowden_Dual_Adapter.step, [a]_blower_housing_front.stl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]
2023-09-07 updated sw cad with fixed X chain toolhead anchor (#61)
2024-01-17 Added diag_pin to Y sensorless homing config example. (#63)
    [skr_mini_e3_v2_config.cfg]
2025-01-23 Update Assembly Manual (#68)
    * Update Assembly Manual
    Fixes issue: #43 #66 #67
    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
